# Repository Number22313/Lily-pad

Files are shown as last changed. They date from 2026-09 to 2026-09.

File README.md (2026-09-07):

# Lily-pad

## 3D Cad Model

This was made in Fusion 360 which luckily I have a lot of experience in so the case didn't take as long as the PCB.

## PCB Schematic

The first iteration used normal manual wiring but after adding the encoder and screen I ran out of pins so I had to resort to learning about matrixes and therefore added a 3x3 matrix to save 1 pin.

## PCB

This is the second PCB I made after trying a test one with just 4 buttons and a microcontroller to get used to KiCAD which is why the routing isn't perfect.

## How the case fits together

The top plate is screwed together with the base to hold the PCB inside and a gap for the USB on one side.

## Firmware
The folder for the firmware is titled "alloyed" and uses QMK.

## BOM (Bill of Materials)

### Materials Needed:
* 7x Cherry MX Switches
* 7x White DSA Keycaps
* 7x 1N4148 Diodes
* 1x EC11E Rotary Encoder
* 1x 0.91 Inch OLED Display
* 1x Seeed XIAO RP2040
* 4x M3x16mm Screws

### Materials already owned
* 700g White PLA Filament (for the case)
* Soldering Iron

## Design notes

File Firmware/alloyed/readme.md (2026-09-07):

# alloyed

alloyed

*A short description of the keyboard/project*

* Keyboard Maintainer: [Number22313](https://github.com/Number22313)
* Hardware Supported: *The PCBs, controllers supported*
* Hardware Availability: *Links to where you can find this hardware*

Make example for this keyboard (after setting up your build environment):

    make alloyed:default

Flashing example for this keyboard:

    make alloyed:default:flash

See the [build environment setup](https://docs.qmk.fm/#/getting_started_build_tools) and the [make instructions](https://docs.qmk.fm/#/getting_started_make_guide) for more information. Brand new to QMK? Start with our [Complete Newbs Guide](https://docs.qmk.fm/#/newbs).

## Bootloader

Enter the bootloader in 3 ways:

* **Bootmagic reset**: Hold down the key at (0,0) in the matrix (usually the top left key or Escape) and plug in the keyboard
* **Physical reset button**: Briefly press the button on the back of the PCB - some may have pads you must short instead
* **Keycode in layout**: Press the key mapped to `QK_BOOT` if it is available

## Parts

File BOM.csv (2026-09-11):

Part Name | Quantity
Cherry MX Switches | 7
White DSA Keycaps | 7
1N4148 Diodes | 7
EC11E Rotary Encoder | 1
0.91 Inch OLED Display | 1
Seeed XIAO RP2040 | 1
M3x16mm Screws | 4

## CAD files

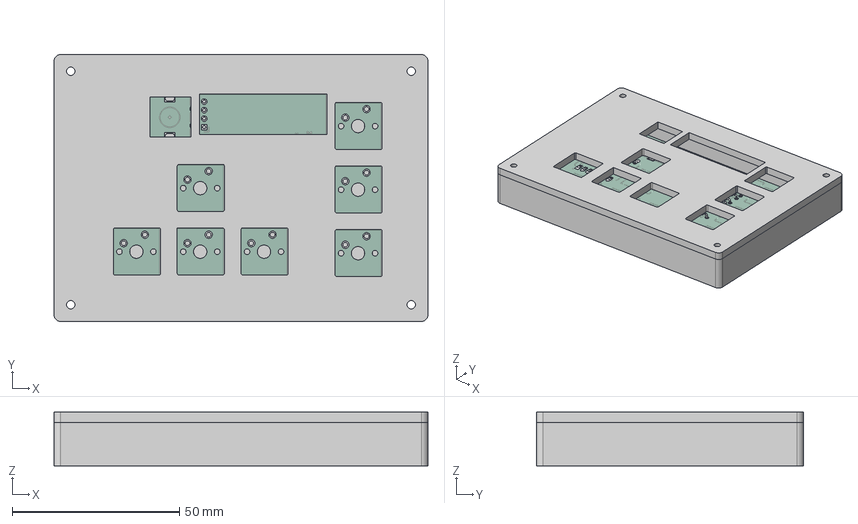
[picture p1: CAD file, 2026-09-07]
CAD/Macropad V2 Cad Model.step
111.8 x 79.8 x 16.0 mm
PCB Case Plate
PCB Board Case
D_DO-35_SOD27_P7.62mm_Horizontal_1 x 7
pcbF90E_copper
pcbF90E_pad
pcbF90E_silkscreen
pcbF90E_soldermask
pcbF90E_soldermask_1
pcbF90E_PCB

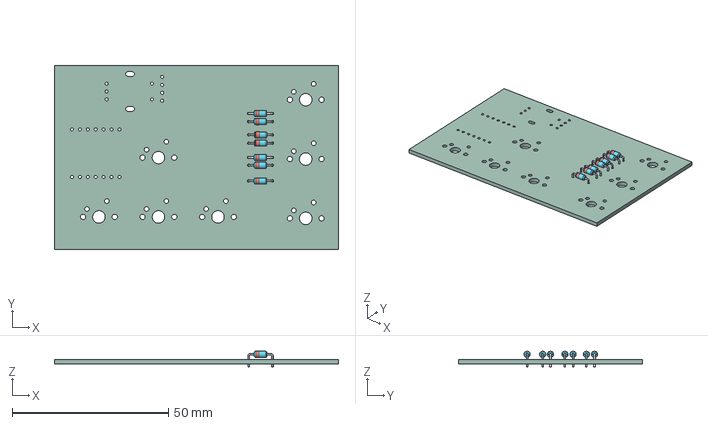
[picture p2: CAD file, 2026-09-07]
PCB/pcb v2.step
91.0 x 59.0 x 5.01 mm
D_DO-35_SOD27_P7.62mm_Horizontal x 7
pcb1A0_PCB

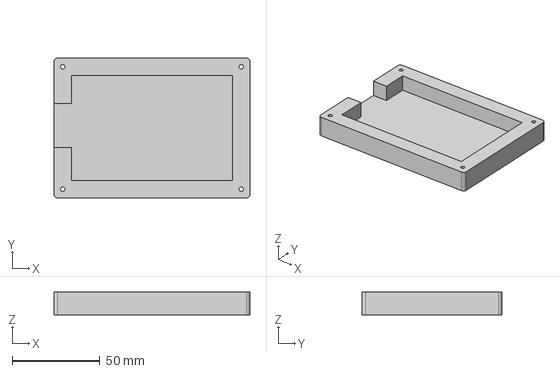
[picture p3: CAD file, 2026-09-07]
Production/Outer Case.step
111.8 x 79.8 x 13.0 mm

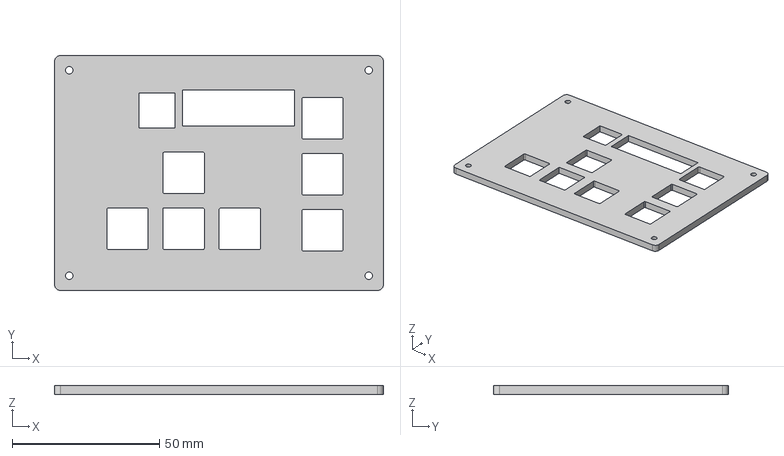
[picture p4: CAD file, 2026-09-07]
Production/Top Plate.step
111.8 x 79.8 x 3.00 mm

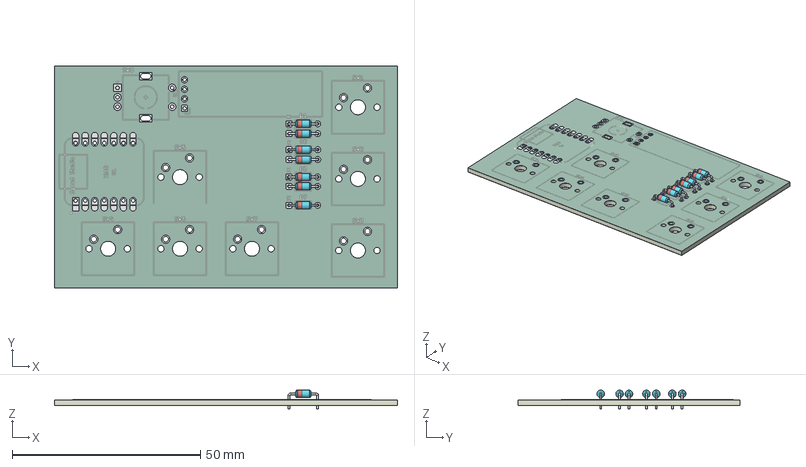
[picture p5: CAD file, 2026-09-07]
Production/PCB.step
91.0 x 59.0 x 5.01 mm
D_DO-35_SOD27_P7.62mm_Horizontal_1 x 7
pcbF90E_copper
pcbF90E_pad
pcbF90E_silkscreen
pcbF90E_soldermask
pcbF90E_soldermask_1
pcbF90E_PCB

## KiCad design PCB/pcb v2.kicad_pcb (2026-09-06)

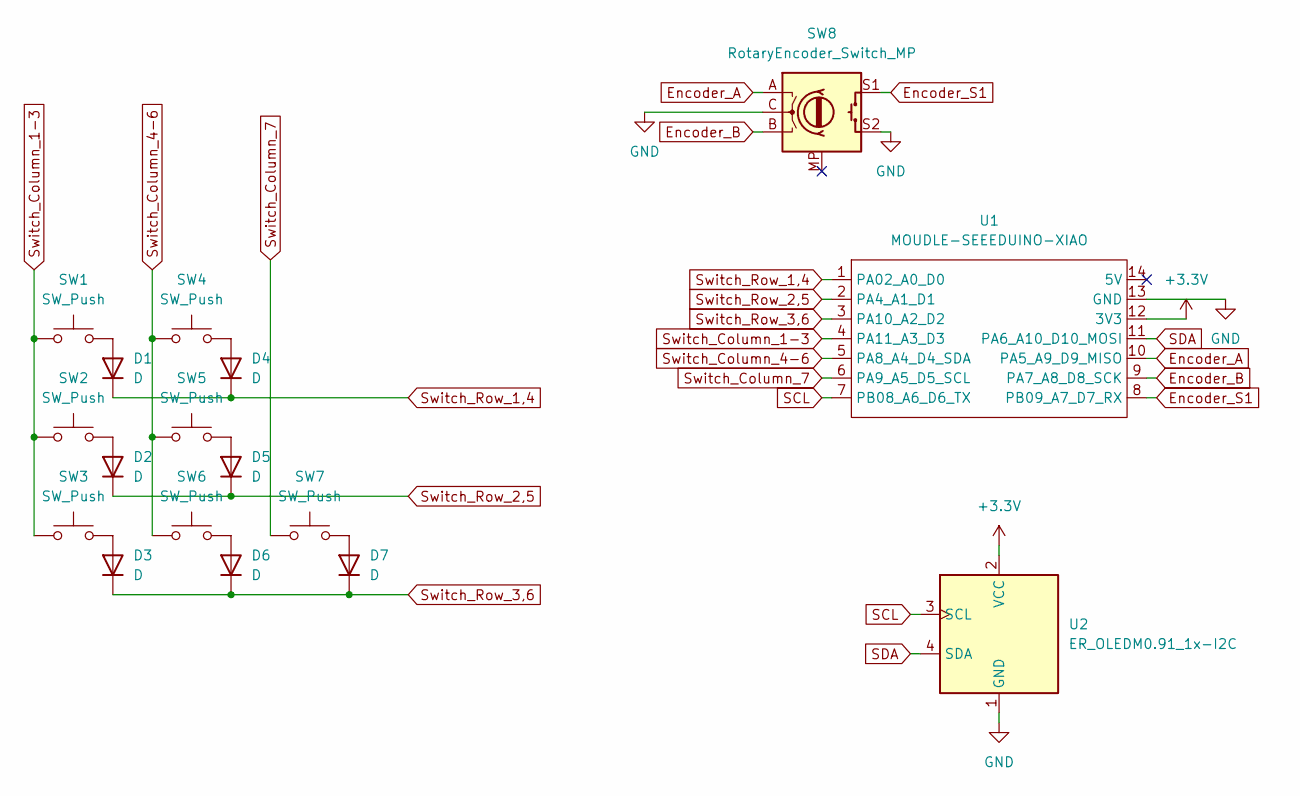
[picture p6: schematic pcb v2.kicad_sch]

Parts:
D1, D2, D3, D4, D5, D6, D7: D; D_DO-35_SOD27_P7.62mm_Horizontal
SW1, SW2, SW3, SW4, SW5, SW6, SW7: SW_Push; SW_Cherry_MX_1.00u_PCB
SW8: RotaryEncoder_Switch_MP; RotaryEncoder_Alps_EC11E-Switch_Vertical_H20mm
U1: MOUDLE-SEEEDUINO-XIAO; XIAO-Generic-Hybrid-14P-2.54-21X17.8MM
U2: ER_OLEDM0.91_1x-I2C

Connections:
+3.3V: U1.12 (3V3), U2.2 (VCC)
Encoder_A: SW8.A, U1.10 (PA5_A9_D9_MISO)
Encoder_B: SW8.B, U1.9 (PA7_A8_D8_SCK)
Encoder_S1: SW8.S1, U1.8 (PB09_A7_D7_RX)
GND: SW8.C, SW8.S2, U1.13 (GND), U2.1 (GND)
unnamed: D1.2 (A), SW1.2
unnamed: D2.2 (A), SW2.2
unnamed: D3.2 (A), SW3.2
unnamed: D4.2 (A), SW4.2
unnamed: D5.2 (A), SW5.2
unnamed: D6.2 (A), SW6.2
unnamed: D7.2 (A), SW7.2
SCL: U1.7 (PB08_A6_D6_TX), U2.3 (SCL)
SDA: U1.11 (PA6_A10_D10_MOSI), U2.4 (SDA)
Switch_Column_1-3: SW1.1, SW2.1, SW3.1, U1.4 (PA11_A3_D3)
Switch_Column_4-6: SW4.1, SW5.1, SW6.1, U1.5 (PA8_A4_D4_SDA)
Switch_Column_7: SW7.1, U1.6 (PA9_A5_D5_SCL)
Switch_Row_1,4: D1.1 (K), D4.1 (K), U1.1 (PA02_A0_D0)
Switch_Row_2,5: D2.1 (K), D5.1 (K), U1.2 (PA4_A1_D1)
Switch_Row_3,6: D3.1 (K), D6.1 (K), D7.1 (K), U1.3 (PA10_A2_D2)

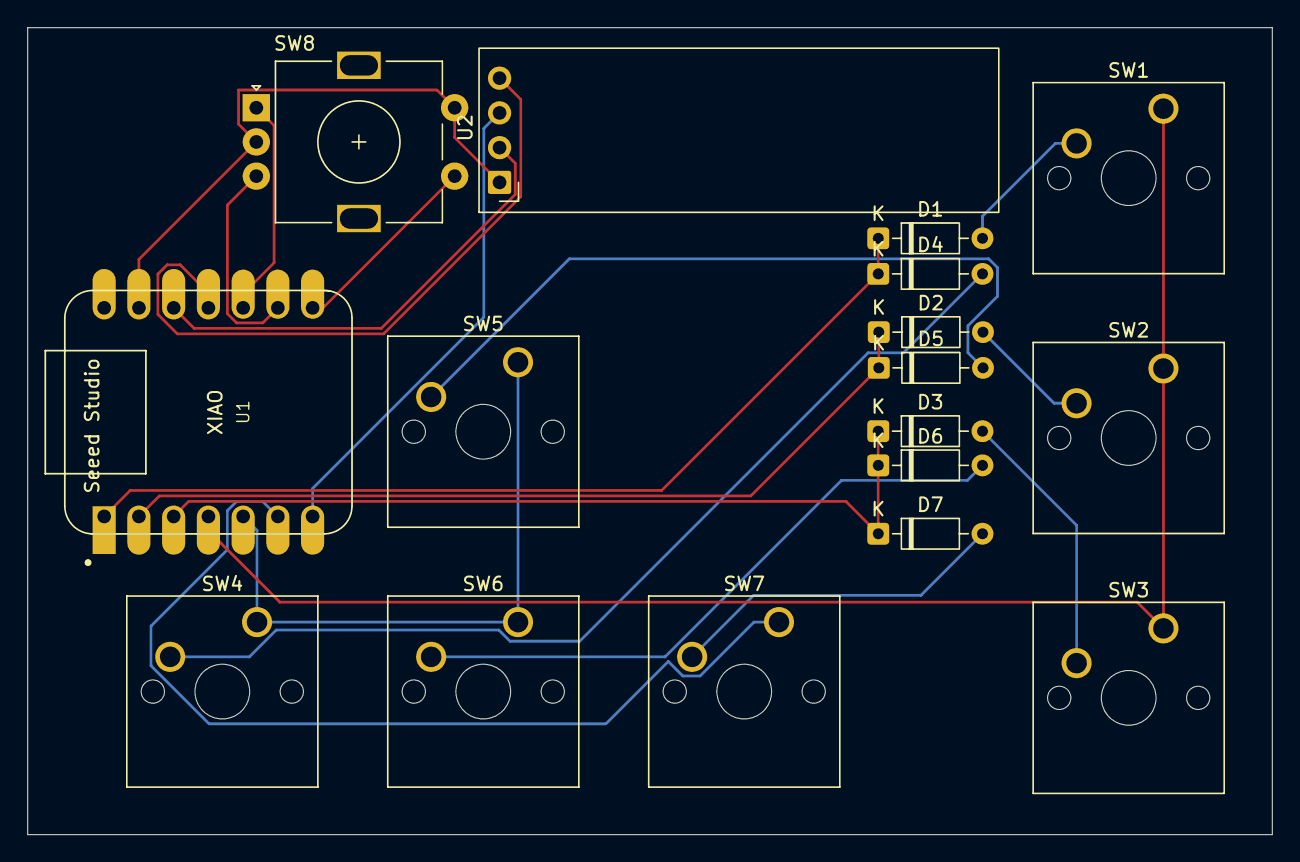
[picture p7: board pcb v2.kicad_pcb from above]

Board: 2 copper layers, 91.0 x 59.0 mm, 17 parts (0 on the bottom side), 20 nets.

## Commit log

2026-09-06 PCB and Case files
    [pcb v2 (Assembly).obj, pcb v2.kicad_pcb, pcb v2.kicad_sch]
2026-09-07 Cleaning up structure
    [pcb v2.kicad_sch]
2026-09-07 Restructured the files
    [Macropad V2 Cad Model.step, Outer Case.step, PCB.step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]
2026-09-07 Restrucuted files into folders for CAD,Firmware,PCB
    [Macropad V2 Cad Model.step, pcb v2.kicad_pcb, pcb v2.kicad_sch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]
2026-09-11 Added the BOM.csv and gerber.zip
    [BOM.csv]
